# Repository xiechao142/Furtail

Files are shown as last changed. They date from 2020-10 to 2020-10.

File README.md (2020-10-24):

# Furtail
An animatronic tail for cosplay use

Servo pins are on D5 and D11 on Huaduino or normal arduino UNO/NANO.

For IMU version, it uses MPU6050 which use D2 as interrupt pin and A4 A5 as I2C port.

MPU6050 lib is needed. https://github.com/jrowberg/i2cdevlib/tree/master/Arduino/MPU6050

You might need to get the IMU offsets first and change them in the IMU code,then download it to the chip. So that it will work properly.

You can download the IMU code into the chip first, open the Serial monitor on PC (Arduino IDE), wait for the offsets data show up.

For bluetooth (BT) version, it uses HC-05 BT module to communicate to the chip through hardware Serial on UNO/NANO (tx0 rx0).

After connected the BT module(you can use bt-serial helper on smartphone), send numbers to make different moves, check the code for more detailed informations.

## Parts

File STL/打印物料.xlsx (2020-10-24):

序号 / No. | 零件 / Parts | 数量 / Quantities | 材料/Material | 支撑 / Supports | 填充率 / lnfills(%)
1 | B1 | 1 | PLA | × | 20
2 | F3 | 1 | PLA | × | 20
3 | F4 | 1 | PLA | × | 20
4 | F5 | 1 | PLA | × | 20
5 | F6 | 1 | PLA | × | 20
6 | F7 | 1 | PLA | × | 20
7 | F1 | 1 | PLA | ✔ | 15
8 | F2 | 1 | PLA | ✔ | 15
9 | T2 | 12 | PLA | ✔ | 15
10 | C1 | 2 | PLA | ✔ | 25
11 | T1 | 1 | PLA | ✔ | 25
12 | T3 | 1 | PLA | ✔ | 25
13 | T4 | 1 | PLA | ✔ | 25
14 | S1 | 2 | TPU | × | 50
8 | 舵机mg966r+配件 | 8
9 | huaduino+锂电池 | 1
10 |  | 6

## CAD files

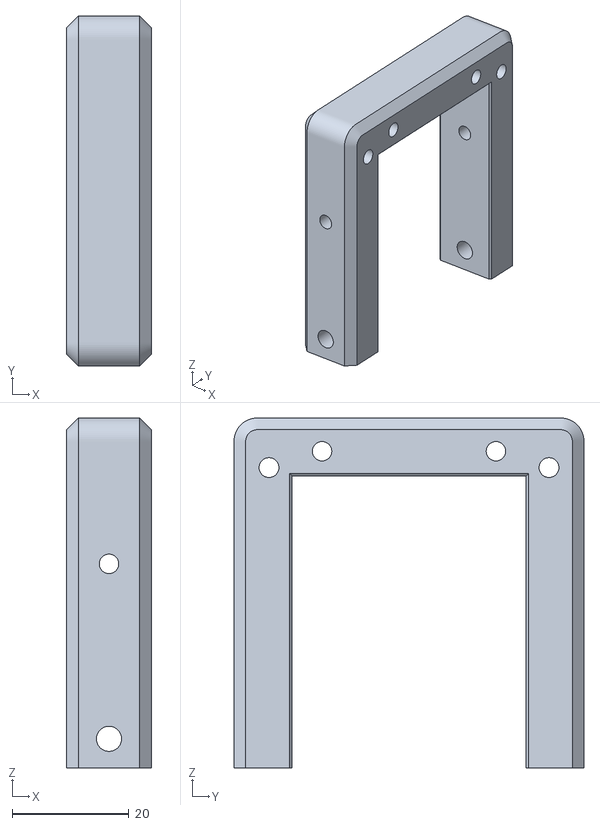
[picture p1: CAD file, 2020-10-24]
STL/F7.stl
14.5 x 60.0 x 60.0

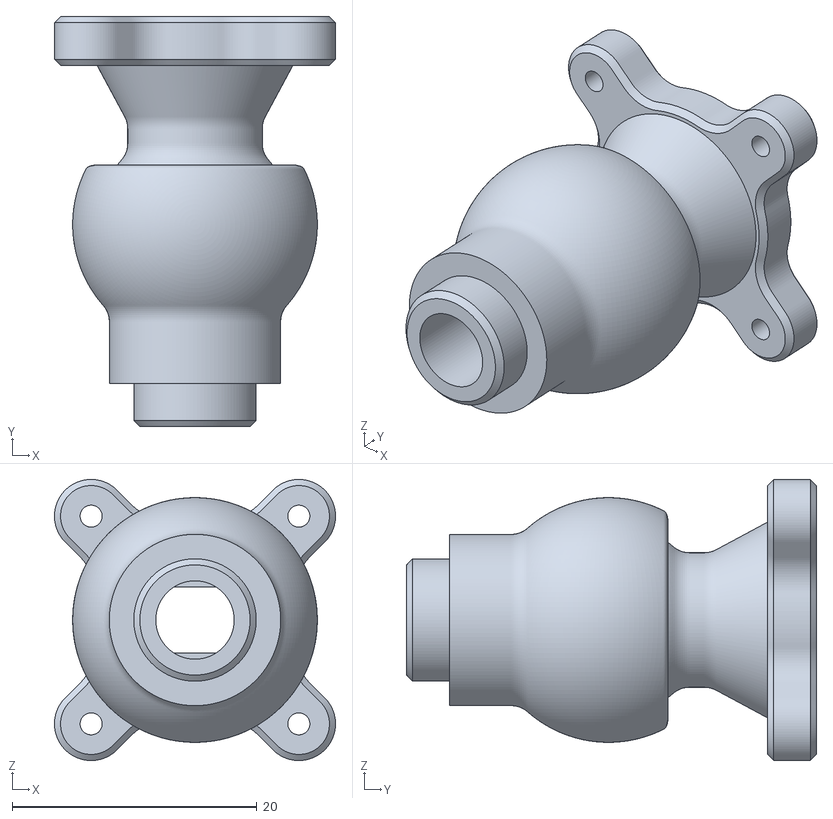
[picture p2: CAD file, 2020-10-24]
STL/T2.stl
23.0 x 33.5 x 23.0

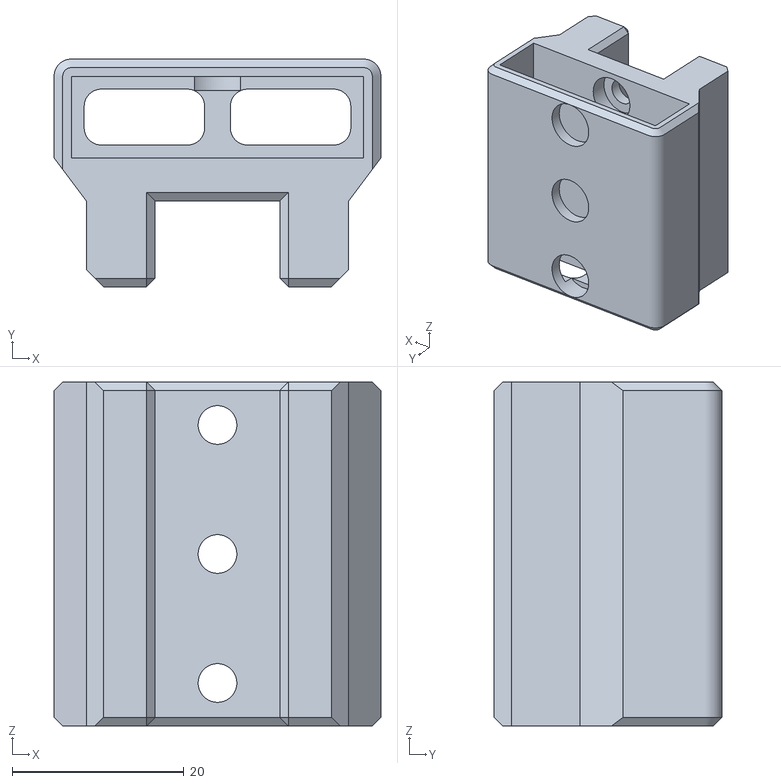
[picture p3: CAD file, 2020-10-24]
STL/F4.stl
38.0 x 26.5 x 40.0

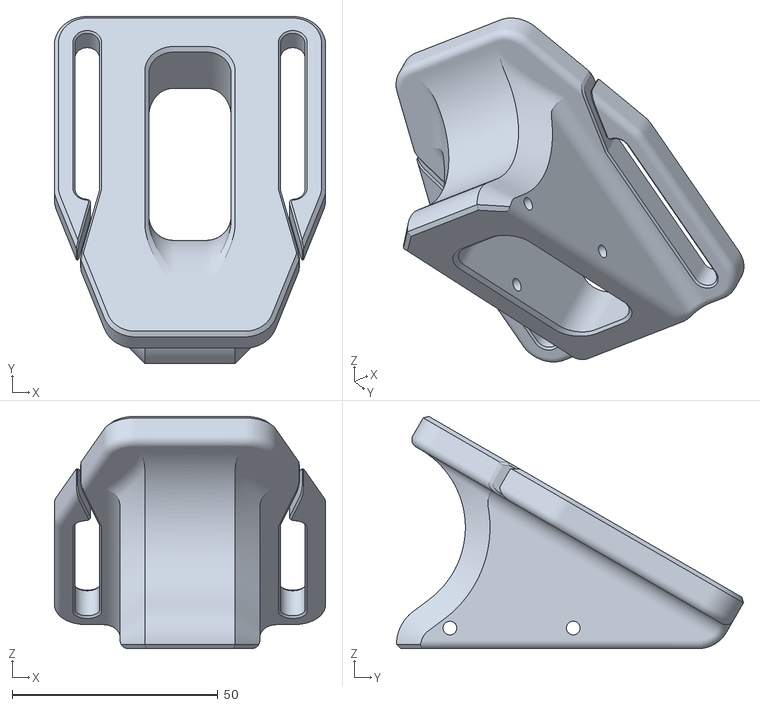
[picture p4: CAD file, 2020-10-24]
STL/B1.stl
66.0 x 84.4 x 56.5

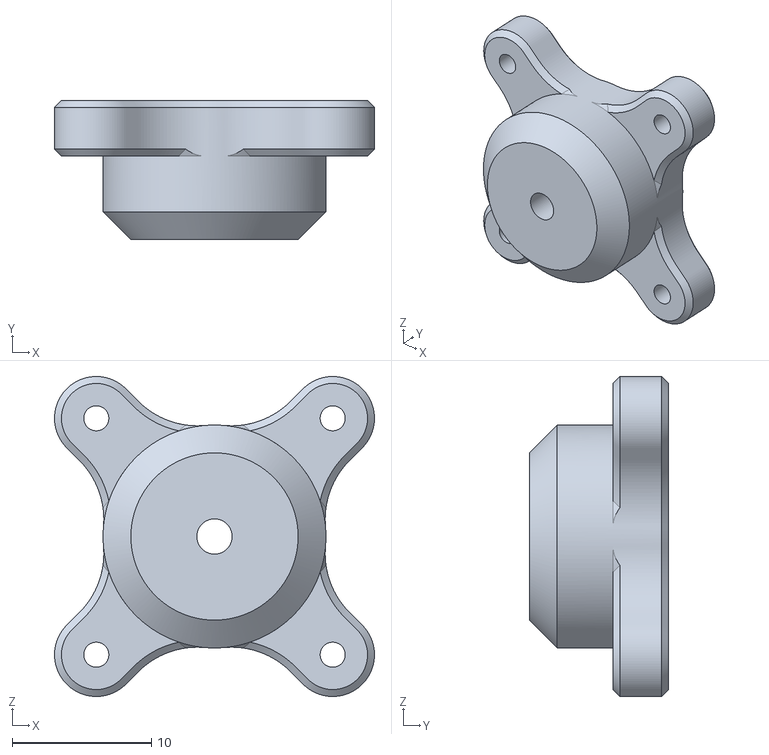
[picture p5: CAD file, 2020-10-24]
STL/T3.stl
23.0 x 10.0 x 23.0

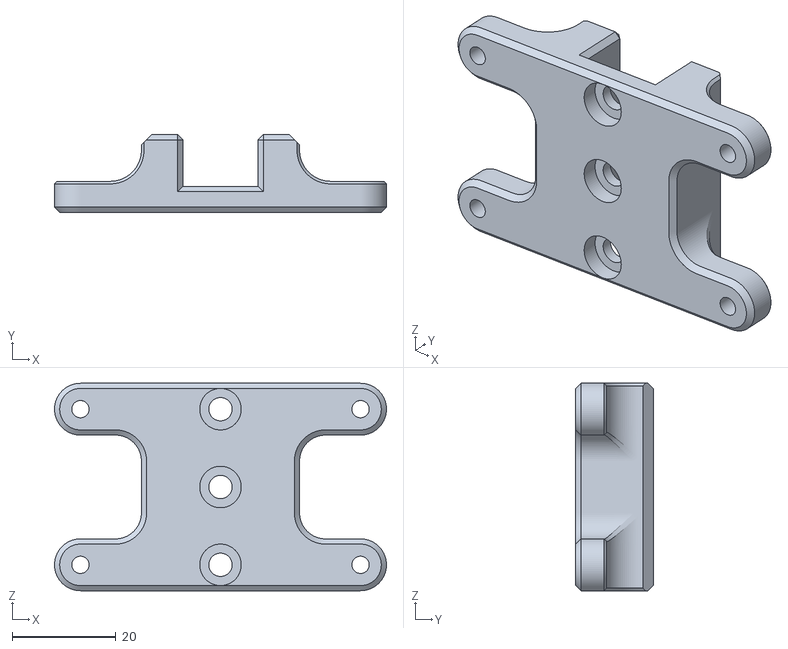
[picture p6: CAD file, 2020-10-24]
STL/F5.stl
64.0 x 15.0 x 40.0

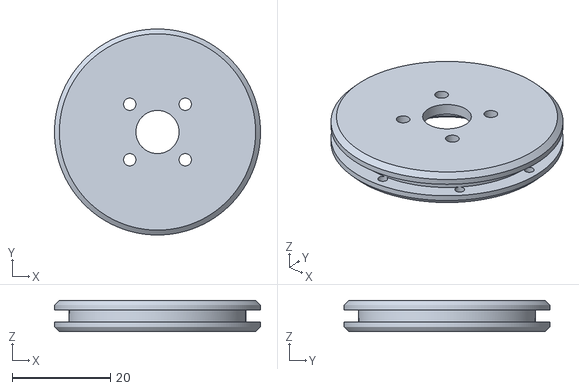
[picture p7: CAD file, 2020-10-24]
STL/C1.stl
42.0 x 42.0 x 6.40

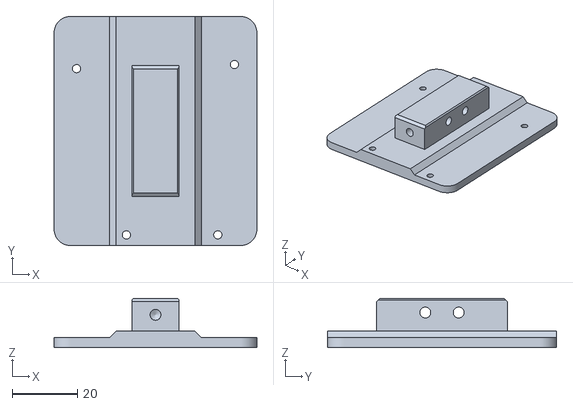
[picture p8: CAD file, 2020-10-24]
STL/F6.stl
62.0 x 70.0 x 15.0

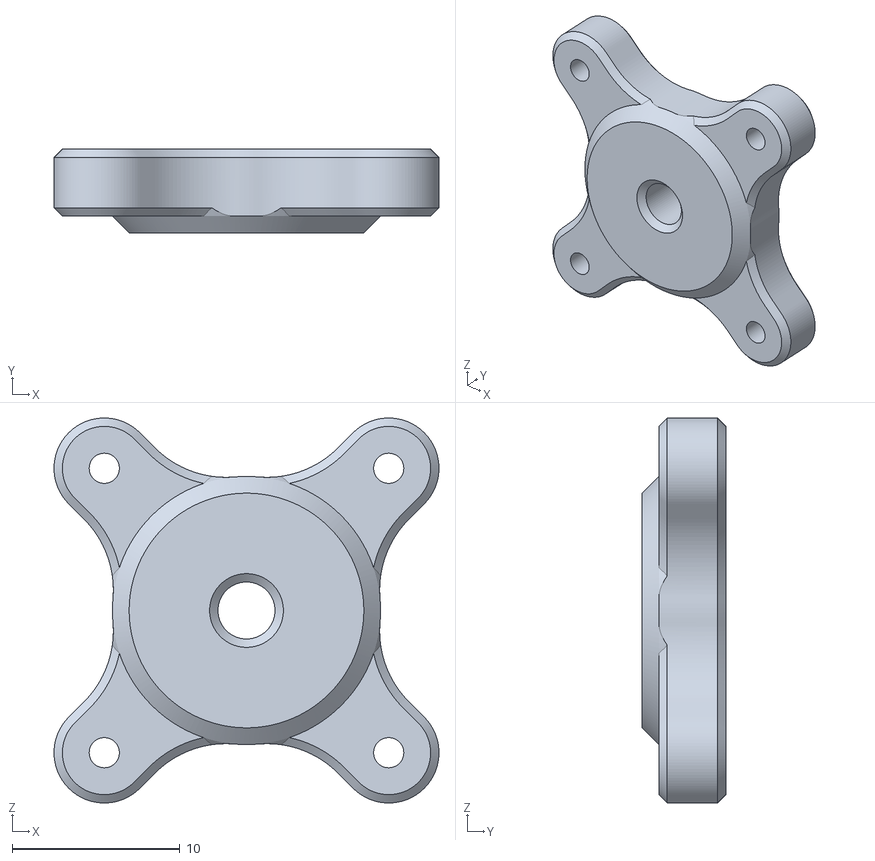
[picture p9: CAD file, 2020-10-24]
STL/T4.stl
23.0 x 5.00 x 23.0

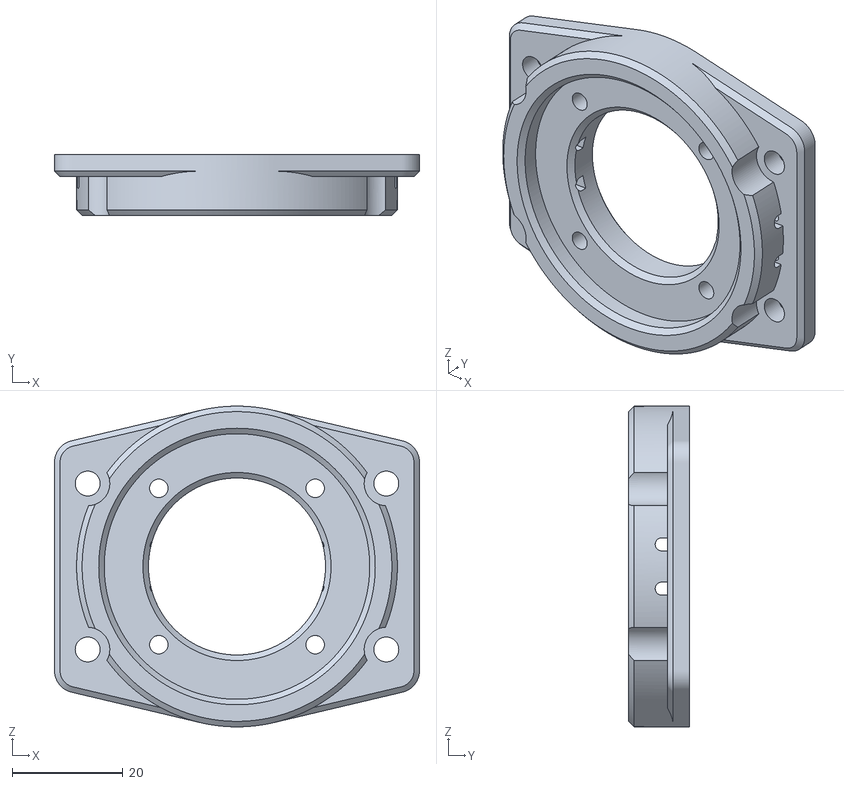
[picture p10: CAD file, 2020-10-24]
STL/F3.stl
66.0 x 11.0 x 58.0

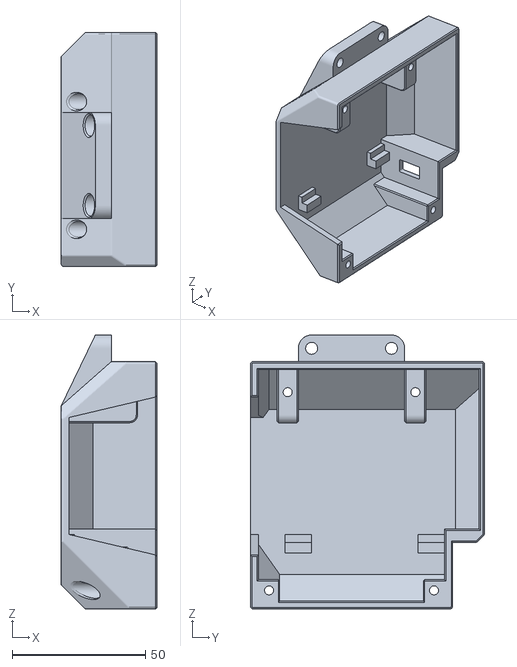
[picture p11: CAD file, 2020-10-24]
STL/F2.stl
36.0 x 88.0 x 103.0

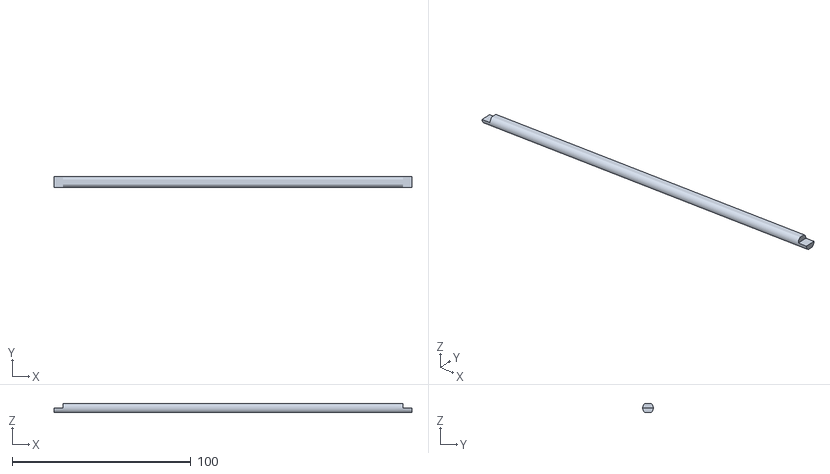
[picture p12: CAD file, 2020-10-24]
STL/S1.stl
200.0 x 6.00 x 5.20

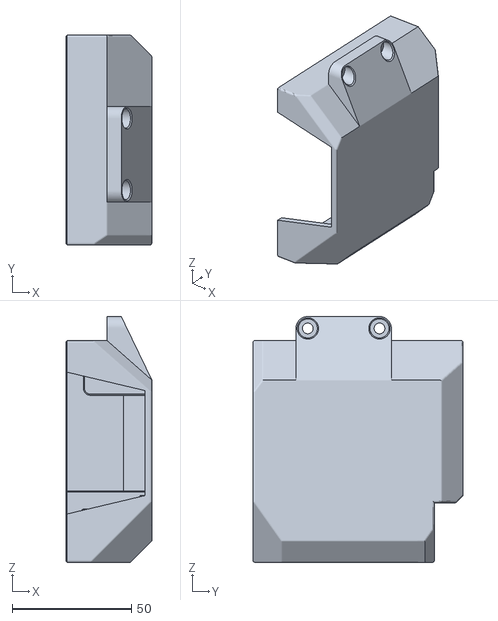
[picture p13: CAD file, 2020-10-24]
STL/F1.stl
36.0 x 88.0 x 103.0

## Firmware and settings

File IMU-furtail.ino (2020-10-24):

#include "I2Cdev.h"
#include "MPU6050_6Axis_MotionApps20.h"
#if I2CDEV_IMPLEMENTATION == I2CDEV_ARDUINO_WIRE
#include "Wire.h"
#endif

MPU6050 mpu;

#define INTERRUPT_PIN 2

#define XaccOFFSET  2147
#define YaccOFFSET  -995
#define ZaccOFFSET   2141
#define XgryoOFFSET  -63
#define YgryoOFFSET 163
#define ZgryoOFFSET 40

 

volatile bool mpuInterrupt = false;     // indicates whether MPU interrupt pin has gone high
void dmpDataReady() {
  mpuInterrupt = true;
}

// MPU control/status vars
bool dmpReady = false;  // set true if DMP init was successful
uint8_t mpuIntStatus;   // holds actual interrupt status byte from MPU
uint8_t devStatus;      // return status after each device operation (0 = success, !0 = error)
uint16_t packetSize;    // expected DMP packet size (default is 42 bytes)
uint16_t fifoCount;     // count of all bytes currently in FIFO
uint8_t fifoBuffer[64]; // FIFO storage buffer

Quaternion q;           // [w, x, y, z]         quaternion container
VectorInt16 aa;         // [x, y, z]            accel sensor measurements
VectorInt16 aaReal;     // [x, y, z]            gravity-free accel sensor measurements
VectorInt16 aaWorld;    // [x, y, z]            world-frame accel sensor measurements
VectorFloat gravity;    // [x, y, z]            gravity vector
float euler[3];         // [psi, theta, phi]    Euler angle container
float ypr[3];           // [yaw, pitch, roll]   yaw/pitch/roll container and gravity vector

float pypr[3];          // previous ypr
float eypr[3];          // ypr error
float sum_e;            // error sum

int Lefturn_TH =          8 ;
int Rightturn_TH =       -8 ;
int Upturn_TH =           8 ;
int Downturn_TH =        -20 ;
int sum_TH =              15 ;

int counts = 0;

#include <Servo.h>
Servo servo_2;
Servo servo_8;




void setup() {
  // put your setup code here, to run once:

  servo_2.attach(5);
    servo_8.attach(11);

      servo_8.write(90);
      servo_2.write(90);
      delay(500);

#if I2CDEV_IMPLEMENTATION == I2CDEV_ARDUINO_WIRE
  Wire.begin();
  Wire.setClock(400000); // 400kHz I2C clock. Comment this line if having compilation difficulties
#elif I2CDEV_IMPLEMENTATION == I2CDEV_BUILTIN_FASTWIRE
  Fastwire::setup(400, true);
#endif

  Serial.begin(9600);
  while (!Serial); // wait for Leonardo enumeration, others continue immediately

  //Serial.println(F("Initializing I2C devices..."));
  mpu.initialize();
  pinMode(INTERRUPT_PIN, INPUT);

  // verify connection
  //Serial.println(F("Testing device connections..."));
  //Serial.println(mpu.testConnection() ? F("MPU6050 connection successful") : F("MPU6050 connection failed"));

  // wait for ready
  /*
  Serial.println(F("\nSend any character to begin DMP programming and demo: "));
  while (Serial.available() && Serial.read()); // empty buffer
  while (!Serial.available());                 // wait for data
  while (Serial.available() && Serial.read()); // empty buffer again
  */

  // load and configure the DMP
  //Serial.println(F("Initializing DMP..."));
  devStatus = mpu.dmpInitialize();

  // supply your own gyro offsets here, scaled for min sensitivity
    mpu.setXGyroOffset(XgryoOFFSET);
    mpu.setYGyroOffset(XgryoOFFSET);
    mpu.setZGyroOffset(XgryoOFFSET);
    mpu.setXAccelOffset(XaccOFFSET);
    mpu.setYAccelOffset(YaccOFFSET);
    mpu.setZAccelOffset(ZaccOFFSET);

  // make sure it worked (returns 0 if so)
  if (devStatus == 0) {
    // Calibration Time: generate offsets and calibrate our MPU6050
    mpu.CalibrateAccel(6);
    mpu.CalibrateGyro(6);
    //Serial.println();
    mpu.PrintActiveOffsets();
    // turn on the DMP, now that it's ready
    //Serial.println(F("Enabling DMP..."));
    mpu.setDMPEnabled(true);
    delay(500);

    // enable Arduino interrupt detection
    //Serial.print(F("Enabling interrupt detection (Arduino external interrupt "));
    //Serial.print(digitalPinToInterrupt(INTERRUPT_PIN));
    //Serial.println(F(")..."));
    attachInterrupt(digitalPinToInterrupt(INTERRUPT_PIN), dmpDataReady, RISING);
    mpuIntStatus = mpu.getIntStatus();

    // set our DMP Ready flag so the main loop() function knows it's okay to use it
    //Serial.println(F("DMP ready! Waiting for first interrupt..."));
    dmpReady = true;

    // get expected DMP packet size for later comparison
    packetSize = mpu.dmpGetFIFOPacketSize();
  } else {
    // ERROR!
    // 1 = initial memory load failed
    // 2 = DMP configuration updates failed
    // (if it's going to break, usually the code will be 1)
    //Serial.print(F("DMP Initialization failed (code "));
    //Serial.print(devStatus);
    //Serial.println(F(")"));
  }
      servo_8.write(45);
      servo_2.write(135);
      delay(1000);

}

void loop() {
  // if programming failed, don't try to do anything
  if (!dmpReady) return;
  // read a packet from FIFO
  if (mpu.dmpGetCurrentFIFOPacket(fifoBuffer)) { // Get the Latest packet 

    // display Euler angles in degrees
    mpu.dmpGetQuaternion(&q, fifoBuffer);
    mpu.dmpGetGravity(&gravity, &q);
    mpu.dmpGetYawPitchRoll(ypr, &q, &gravity);

    

    for(int i=0;i<3;i++){
      eypr[i] = (ypr[i]-pypr[i]) * 180 / M_PI;
      pypr[i] = ypr[i];    
    }

    sum_e = eypr[0]+ eypr[1]+ eypr[2] ;

  /*
    Serial.print("Error ypr\t");
    Serial.print(eypr[0]);
    Serial.print("\t");
    Serial.print(eypr[1]);
    Serial.print("\t");
    Serial.print(eypr[2]);
    Serial.print("\t");
    Serial.print(sum_e);
    Serial.println();
  */
  

    if (eypr[2] < Rightturn_TH) {
      servo_8.write(10);
      servo_2.write(40);
      //delay(100);
      counts = 0;
    }

    if (eypr[2] > Lefturn_TH) {
      servo_8.write(140);
      servo_2.write(170);
      //delay(100);
      counts = 0;
    }

    if (eypr[1] > Upturn_TH) {
      servo_8.write(0);
      servo_2.write(180);
      //delay(100);
      counts = 0;
    }

    if (eypr[1] < Downturn_TH) {
      servo_8.write(170);
      servo_2.write(10);
      //delay(100);
      counts = 0;
    }

    if (sum_e < sum_TH){
      counts++;
    }

    if (counts > 30){
      servo_8.write(60);
      servo_2.write(120);
      counts = 0;
    }

  }

  delay(200);


}

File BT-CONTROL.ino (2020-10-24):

#include <Servo.h>

char BT;


Servo servo_2;
Servo servo_8;

void setup(){
  Serial.begin(9600);
  servo_2.attach(5);
  servo_8.attach(11);
}

void loop(){
  if (Serial.available() > 0) {
    BT = Serial.read();
    Serial.println(BT);
    if (BT == '0') {
      Serial.println("STOP");
      servo_2.write(90);
      //delay(0);
      servo_8.write(90);
      delay(500);

    }
    if (BT == '1') {
      Serial.println("UP");
      servo_2.write(135);
      //delay(0);
      servo_8.write(45);
      delay(500);

    }
    if (BT == '2') {
      Serial.println("DOWN");
      servo_8.write(135);
      //delay(0);
      servo_2.write(45);
      delay(500);

    }

    if (BT == '3') {
      Serial.println("TOP");
      servo_8.write(20);
      //delay(0);
      servo_2.write(160);
      delay(500);

    }

    if (BT == '4') {
      Serial.println("BOTTOM");
      servo_8.write(160);
      //delay(0);
      servo_2.write(20);
      delay(500);

    }

    if (BT == '5') {
      Serial.println("LEFT");
      servo_8.write(20);
      //delay(0);
      servo_2.write(90);
      delay(500);

    }

    if (BT == '6') {
      Serial.println("RIGHT");
      servo_8.write(90);
      //delay(0);
      servo_2.write(160);
      delay(500);

    }
    if (BT == '7') {
      Serial.println("UP RIGHT");
      servo_8.write(45);
      //delay(0);
      servo_2.write(175);
      delay(500);

    }
    if (BT == '8') {
      Serial.println("UP LEFT");
      servo_8.write(5);
      //delay(0);
      servo_2.write(45);
      delay(500);

    }

    if (BT == '9') {
      Serial.println("SWING");

        servo_8.write(10);
        //delay(0);
        servo_2.write(170);
        delay(500);
      
      for(int i = 0;i <5;i++){
        
        servo_8.write(5);
        servo_2.write(90);
        delay(500);

        servo_8.write(90);
        servo_2.write(175);
        delay(500);

      }
      servo_8.write(10);
        //delay(0);
        servo_2.write(170);
        delay(500);

    }

  }
  if (BT == 'a') {
      Serial.println("test");
      while(1){
        
        servo_2.write(170);
        servo_8.write(10);
        delay(1200);

        servo_8.write(170);
        servo_2.write(10);
        delay(1200);
      }

    }

}
